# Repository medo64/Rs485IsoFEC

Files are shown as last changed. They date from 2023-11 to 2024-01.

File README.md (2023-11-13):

[Isolated RS-485 Framework Expansion Card](https://medo64.com/rs485isofec/)
===========================================================================

This Framework laptop expansion card will show up on your system as a serial
device and allow for isolated RS-485 communication up to 460,800 baud rate.

Please note that this card is using automatic transmit control and 120Ω
termination.

## Pinout

To connect to this board, one has to use a 4-pin JST XH connector. The following
table represents the pinout, pin 1 being on the left as looking into the
expansion card.

| # | Ref | Description |
|--:|-----|---|
| 1 | GND | Ground connection |
| 2 | A | Negative (low for logic 1 and high for logic 0) |
| 3 | B | Positive (high for logic 1 and low for logic 0) |
| 4 | NC  | Not connected |

As power consumption is low, wires can be almost any AWG. I would recommend
using 24 AWG wire 0.25 mm² as they allow for greater compatibility with other
connectors.

## Supported Speeds

This board employs the FT232R as its UART chip, and consequently, it supports
all the baud rates this chip [can handle](https://ftdichip.com/Documents/AppNotes/AN232B-05_BaudRates.pdf)
up to 500,000 baud which is the limit of isolator chip used. The table below
lists the standard baud rates.

| Baud rate | Actual | Error | Divisor |
|---:|---:|---:|---:|
| 300 | 300 | 0.00% |  10000.000 |
| 600 | 600 | 0.00% | 5000.000 |
| 1,200 | 1,200 | 0.00% | 2500.000 |
| 1,800 | 1,800 | 0.00% | 1666.625 |
| 2,400 | 2,400 | 0.00% | 1250.000 |
| 4,800 | 4,800 | 0.00% | 625.000 |
| 7,200 | 7,201 | 0.01% | 416.625 |
| 9,600 | 9,600 | 0.00% | 312.500 |
| 14,400 | 14,406 | 0.04% | 208.250 |
| 19,200 | 19,200 | 0.00% | 156.250 |
| 28,800 | 28,812 | 0.04% | 104.125 |
| 38,400 | 38,400 | 0.00% | 78.125 |
| 57,600 | 57,692 | 0.16% | 52.000 |
| 115,200 | 115,385 | 0.16% | 26.000 |
| 230,400 | 230,769 | 0.16% | 13.000 |
| 460,800 | 461,538 | 0.16% | 6.500 |

While rates above this can be set, they are not guaranteed to work.

---
*You can check my blog and other projects at [www.medo64.com](https://www.medo64.com/electronics/).*

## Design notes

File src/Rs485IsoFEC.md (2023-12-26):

### Rs485IsoFEC Parts

|  # | Part | RefDes  | Preferred Part Number |
|---:|---|---|---|
|  3 | C 10nF X7R 16V (0805) | C1-C3 | 399-17617-1-ND |
|  7 | C 100nF X7R 16V (0805) | C4-C10  | 478-5311-1-ND |
|  1 | C 4.7uF X5R 16V (0805) | C11 | 1276-1244-1-ND |
|  2 | C 10uF X5R 16V (0805) | C12-C13 | 490-16824-1-ND |
|  1 | D TVS SM712 | D1 | SM712-TPMSCT-ND |
|  2 | DS LED (0805) | DS1-DS2 | 475-1415-1-ND |
|  1 | J JST XH Vertical (4w) | J1 | 455-B4B-XH-A-ND |
|  1 | L Ferrite 600R@100Mhz | L1 | 240-2390-1-ND |
|  1 | P USB C, plug, straddle 0.8mm | P1 | WM12855-ND |
|  1 | Q P-MOSFET DMP3099L-13 (SOT23) | Q1 | DMP3099L-13DICT-ND |
|  1 | R 120 0.125W (0805) | R1 | RMCF0805FT120RCT-ND |
|  3 | R 1K 0.125W (0805) | R2-R4 | RMCF0805FT1K00CT-ND |
|  1 | R 5.1K 0.125W (0805) | R5 | RMCF0805FT5K10CT-ND |
|  1 | R 10K 0.125W (0805) | R6 | RMCF0805FT10K0CT-ND |
|  1 | U FT232R (SSOP-28) | U1 | 768-FT232RNL-TUBE-ND |
|  1 | U ADM2687E (SOIC-16) | U2 | 505-ADM2687EBRIZ-RL7CT-ND  |
|  2 | H Screw M2x3mm | - | - |

#### Board Size

| | Dimensions | Area | Thickness |
|---|---|---|---|
| PCB |  24.0 x 27.9 mm | 1.1 in² | 0.8 mm |

#### FTDI Configuration

| Setting | Value  |
|---|---|
| CBUS0 | TXLED# |
| CBUS1 | RXLED# |
| CBUS2 | TXDEN  |
| CBUS3 | PWREN# |
| CBUS4 | SLEEP# |

#### FTDI Configuration

| Setting | Value  |
|---|---|
| CBUS0 | TXLED# |
| CBUS1 | RXLED# |
| CBUS2 | TXDEN  |
| CBUS3 | PWREN# |
| CBUS4 | SLEEP# |

#### Power

| Property | Value  |
|---|---:|
| Voltage  | 5 V |
| Current  | 210 mA |

#### Termination

To remove termination, desolder termination resistor on top of the board (marked
`TERM`).

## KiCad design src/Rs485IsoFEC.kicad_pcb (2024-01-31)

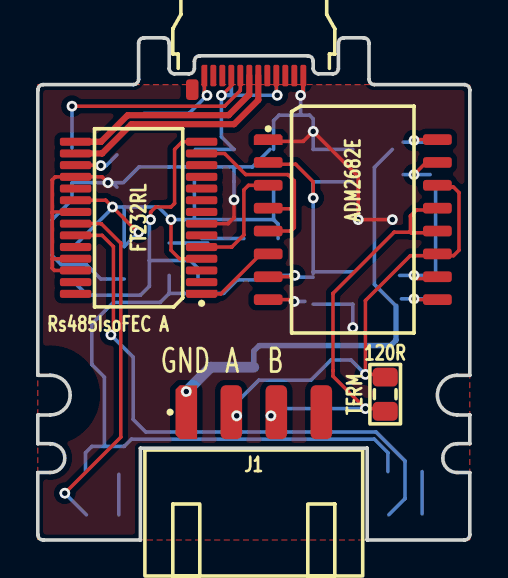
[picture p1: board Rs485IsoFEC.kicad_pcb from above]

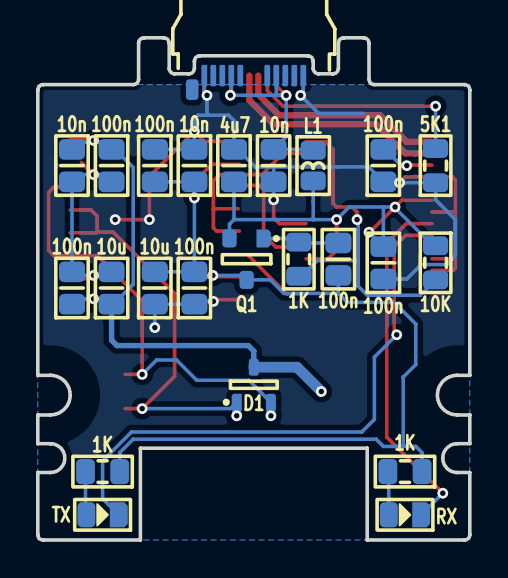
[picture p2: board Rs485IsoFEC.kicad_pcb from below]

Board: 2 copper layers, 24.0 x 27.9 mm, 28 parts (23 on the bottom side), 21 nets.

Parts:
C1, C2, C3: 10n; C (0805)
C4, C5, C6, C7, C8, C9, C10: 100n; C (0805)
C11: 4u7; C (0805)
C12, C13: 10u; C (0805)
D1: SM12T1G; D TVS SM05T1G (SOT23-3)
DS1: RX; DS (0805)
DS2: TX; DS (0805)
J1: B4B-XH-A; J JST XH Edge [RS485] (4w)
L1: 600R; L (0805)
P1: 105444-0001; P USB C 3.2 Edge (24w)
Q1: DMP3099L-13; Q MOSFET-P (SOT23-3)
R1: 120R; R (0805)
R2, R3, R4: 1K; R (0805)
R5: 10K; R (0805)
R5#2: 5K1; R (0805)
U1: FT232RL; U Transciever UART FT232RL (SSOP-28)
U2: ADM2682E; U Transciever RS485 Isolated ADM2682E (SOIC-16)

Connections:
3V3: C5.2, U1.17
5V: C4.2, C11.2, L1.1, Q1.2, R5.1, U1.4, U1.20
5V_SW: C2.2, C6.2, C7.2, C9.2, C12.2, Q1.3, R2.1, R3.1, U2.2, U2.7
A_CC: P1.A5, R5#2.2
GND: C1.1, C2.1, C4.1, C5.1, C7.1, C9.1, C11.1, C12.1, P1.A1, P1.A12, P1.B01, P1.B12, R5#2.1, U1.7, U1.18, U1.21, U1.25, U1.26, U2.1, U2.8
ISO_A: D1.2, J1.2, R1.1, U2.11, U2.14
ISO_B: D1.1, J1.3, R1.2, U2.12, U2.13
ISO_GND: C3.1, C8.1, C10.1, C13.1, D1.3, J1.1, U2.9, U2.16
ISO_V+: C3.2, C8.2, C10.2, C13.2, U2.10, U2.15
LED_RXD: DS1.1, U1.22
LED_RXD': DS1.2, R2.2
LED_TXD: DS2.1, U1.23
LED_TXD': DS2.2, R3.2
PWREN#: R4.1, R5.2, U1.14
PWREN#': C6.1, Q1.1, R4.2
RXD: U1.5, U2.3
TXD: U1.1, U2.6
TXDEN: U1.13, U2.4, U2.5
USB_DM: P1.A7, U1.16
USB_DP: P1.A6, U1.15
USB_Vin: C1.2, L1.2, P1.A4, P1.A9, P1.B04, P1.B09

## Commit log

2023-11-13 Removed fail-safe termination
    [Rs485IsoFEC.kicad_pcb]
2023-11-13 Refactoring traces a bit + renaming termination resistor
    [Rs485IsoFEC.kicad_pcb]
2023-11-13 Fixed half-duplex RS-485
    [Rs485IsoFEC.kicad_pcb]
2023-11-13 Refactoring isolator orientation
    [Rs485IsoFEC.kicad_pcb]
2023-11-13 Moving LEDs to bottom
    [Rs485IsoFEC.kicad_pcb]
2023-11-13 Moved termination resistor
    [Rs485IsoFEC.kicad_pcb]
2023-12-26 Added PWREN pullup and moved LED 5V to switched
    [Rs485IsoFEC.kicad_pcb]
2023-12-26 Aligned resistors
    [Rs485IsoFEC.kicad_pcb]
2023-12-26 Removed internal RTS/CTS connection
    [Rs485IsoFEC.kicad_pcb]
2023-12-29 Updated connector to solder all 4 pins
    [Rs485IsoFEC.kicad_pcb]
2023-12-30 Refactoring copper pour
    [Rs485IsoFEC.kicad_pcb]
2024-01-31 Moved board RefDes to top
    [Rs485IsoFEC.kicad_pcb]
